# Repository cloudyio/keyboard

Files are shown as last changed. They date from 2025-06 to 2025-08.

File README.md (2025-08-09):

# Cloudboard



A low profile ergo keyboard inspired by the lily 58.

## Overview

The cloudboard is a small low profile keyboard made to be wireless and bluetooth, it features a lily 58 key layout, 110mAh batteriea im each half and 2 supermini controllers

The keyboard uses ZMK for its firmware due to how simple but effective it is for ergo and bluetooth keyboards.

## Why i made the project

Ive wanted to try out a ergo keyboard for a while now and thought it would be a fun idea to make one with the features i actually want and none of the extra parts.

## Features:

### Simple design

The keyboard is made to be clean and compact with each half only being less then 15cm long, the layout used is also concidered a intro ergo keyboard layout having many similarities to a normal layout which makes it easy to learn!


*Dev board risen to represent height of header*

### NRF52840 Board

The nice!nano is conciderably one of the best boards for a ergo split keyboard, this is due to its small size while still packing bluetooth compatibility, built in battery managment and USB C. One of the biggest issues with the board though is its 20 dollar price point so instead the keyboard uses a replicate alternative which includes **all** the features of the nice!nano (can be found in BOM below).



TLDR:

The dev board allows for bluetooth, usb c and battery managment for less than 4 dollars.

### Low profile

Low profile keyboard are better ergonimically, are smaller, lighter and arguably look better. The keyboard features choc v1 switches to give the board a even lower size profile and sound profile.



## Schematics/PCB

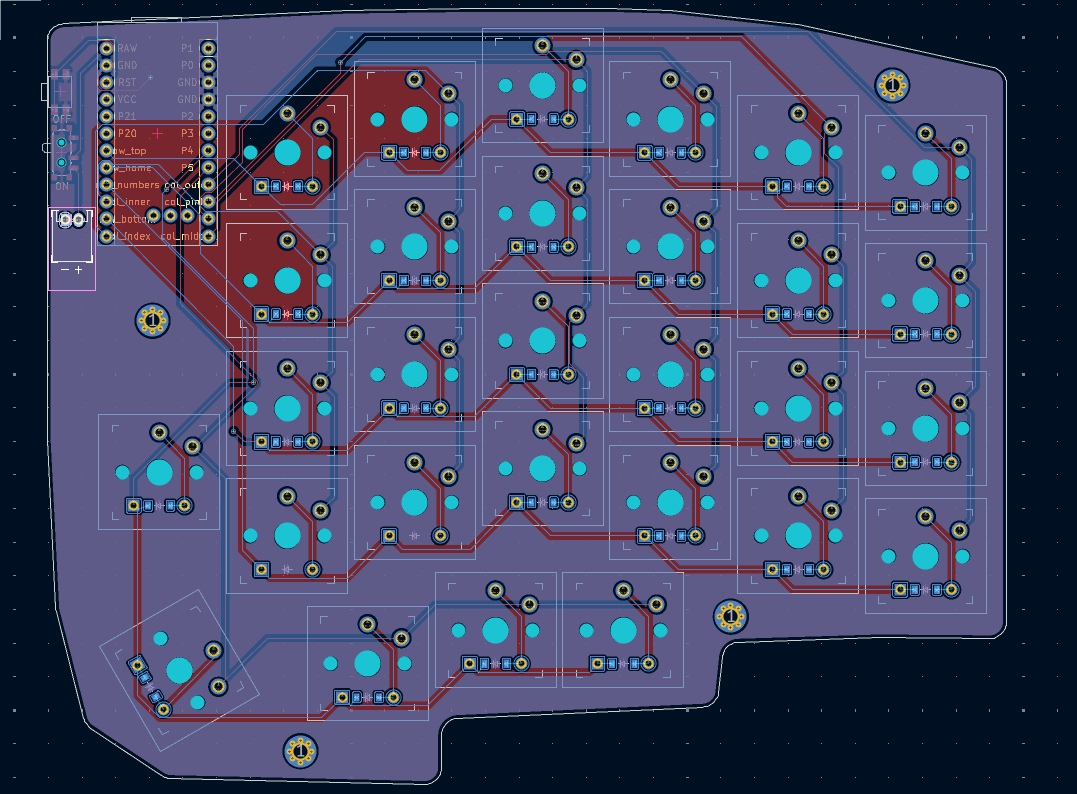
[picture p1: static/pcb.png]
pcb




Both schematics are the exact same





## BOM

| Item | Count | Price Per Item | Total Cost | Source | Notes |
|---|---|---|---|---|---|
| NRF52840 Development Board | 2 | $2.94 | $7.92 | [AliExpress](https://www.aliexpress.com/item/1005001621678794.html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) | Cheap nice!nano + shipping for all of aliexpress items |
| 1N4148 DO-35 Diodes | 1 | $1.58 | $1.58 | [AliExpress](https://www.aliexpress.com/item/1005007131309837.html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) | Diodes |
| Keycap Set | 1 | $32.47 | $32.47 | [AliExpress](https://www.aliexpress.com/item/1005007511714496.html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) | keycap set, quite good quality and look very nice, most price to performacnce i could find |
| JST battery connector  | 1 | $2 | $2 | [AliExpress](https://www.aliexpress.com/item/1005008970428474.html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) | Battery connector, comes with 2 |
| power switch | 1 | $2 | $2 | [AliExpress](https://www.aliexpress.com/item/1005006827258573.html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) | Also comes with 2 |
| Reset tactile button | 2 | $0 | $1 | [AliExpress](https://www.aliexpress.com/item/1005006292427731.html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) | Again, comes with 2 |
| Lithium Battery 110mAh | 1 | $8 | 8$ | [AliExpress](https://www.aliexpress.com/item/1005009279554068.html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) | Pretty cheap batteries, has the pcb integrated and fits under the dev board to stay hidden 2/pc |
| L+R PCB | 1 | $15.00 | $22.00 | [JLCPCB](https://cart.jlcpcb.com/quote?rand=0.6702360434866385) | Both pcbs, includes customs + shipping |
| Kailh Choc v1 Low Profile Switches | 1 | $38 | 38$ | [AliExpress](https://www.aliexpress.com/item/1005006626760418.html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) | Pretty good switches for a good price, only need 60 since keyboard is 58 keys |
| Black fillament | 1 | $18 | $25 | [Amazon](https://www.amazon.co.uk/gp/product/B0CD77VHBZ/ref=sw_img_1?smid=A2AC9IE1506MQ8&psc=1) | Grey fillament that's cheap, includes shipping |
| Heat inserts | 1 | $1.70 | $1.70 | [AliExpress](https://www.aliexpress.com/item/1005008666672949.html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) |  Heat inserts so fillament doesnt get destroyed, they annoyingly only come in 50 but there cheap so its fine anyway |
|  |  |  | $140.79 |  |  |
|  |  |  |  |  |  |
|  |  |  |  |  |  |
|  |  |  |  |  |  |
| |  |  |  |  |  |
notes:

- VAT is included but shipping is not since it varies, will typically end up at arround 7-15 dollars
- to save 5 dollars or so use the panel.zip gerber which is the 2 pcbs connected via mouse bites

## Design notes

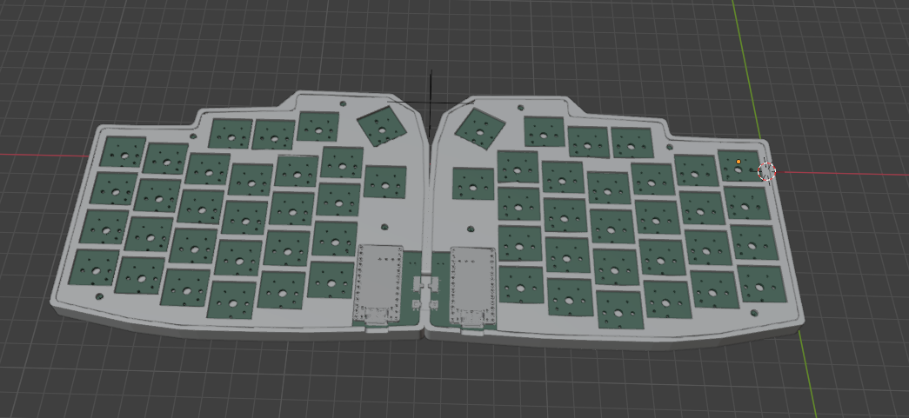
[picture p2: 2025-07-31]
static/image.png

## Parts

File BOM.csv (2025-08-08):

Item | Count | Price Per Item | Total Cost | Source | Notes
NRF52840 Development Board | 2 | $2.94 | $4.56 | https://www.aliexpress.com/item/1005001621678794.html?mp=1 | Cheap nice!nano
1N4148 DO-35 Diodes | 1 | $1.58 | $1.58 | https://www.aliexpress.com/item/1005007131309837.html?mp=1 | Diodes
Keycap Set | 1 | $32.47 | $32.47 | https://www.aliexpress.com/item/1005007511714496.html?mp=1 | keycap set, quite good quality and look very nice, most price to performacnce i could find
JST battery connector | 1 | $2 | $2 | https://www.aliexpress.com/item/1005008970428474.html?mp=1 | Battery connector, comes with 2
power switch | 1 | $2 | $2 | https://www.aliexpress.com/item/1005006827258573.html?mp=1 | Also comes with 2
Reset tactile button | 1 | $0 | $1 | https://www.aliexpress.com/item/1005006292427731.html?mp=1 | Again, comes with 2
Lithium Battery 110mAh | 1 | $8 | 8$ | https://www.aliexpress.com/item/1005009279554068.html?mp=1 | Pretty cheap batteries, has the pcb integrated and fits under the dev board to stay hidden 2/pc
L+R PCB | 1 | $15.00 | $22.00 | https://cart.jlcpcb.com/quote?rand=0.6702360434866385 | Both pcbs, includes customs + shipping
Kailh Choc v1 Low Profile Switches | 1 | $38 | 38$ | https://www.aliexpress.com/item/1005006626760418.html?mp=1 | Pretty good switches for a good price, only need 60 since keyboard is 58 keys
Black fillament | 1 | $18 | $18 | https://a.co/d/5nH2rc7 | Grey fillament thats cheap, only one i could find in budget
Heat inserts | 1 | $1.70 | $1.70 | https://www.aliexpress.com/item/1005008666672949.html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 | Heat inserts so fillament doesnt get destroyed, they annoyingly only come in 50 but there cheap so its fine anyway
 |  |  | $130.42

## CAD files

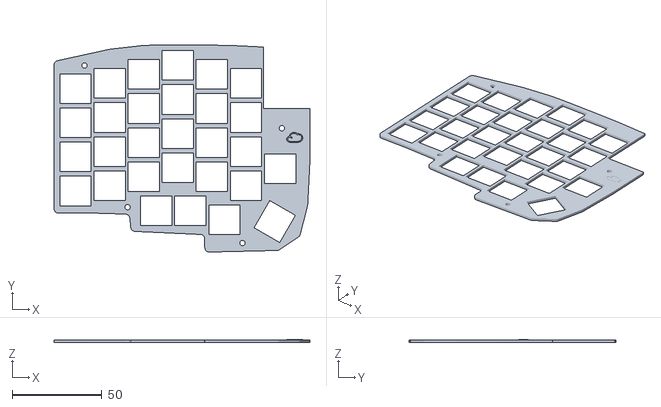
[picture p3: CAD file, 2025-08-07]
production/left/case/PlateL.stl
142.6 x 115.4 x 1.85

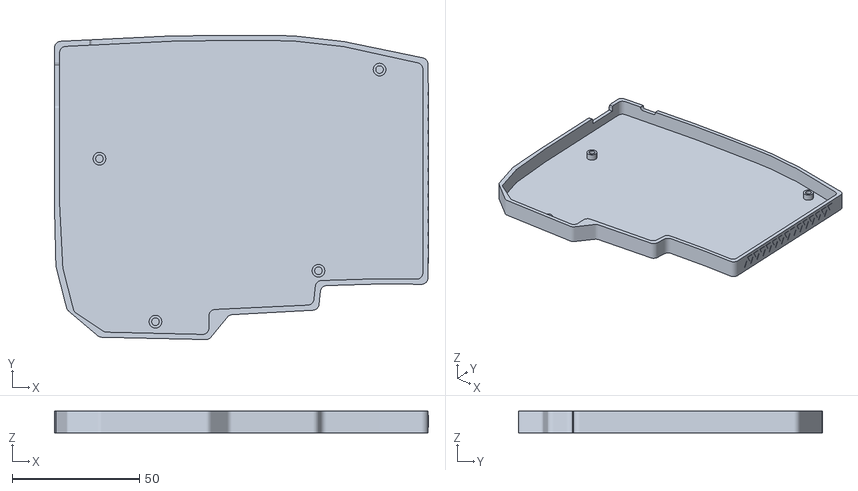
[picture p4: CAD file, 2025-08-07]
production/right/case/CaseR.stl
146.9 x 119.4 x 8.50

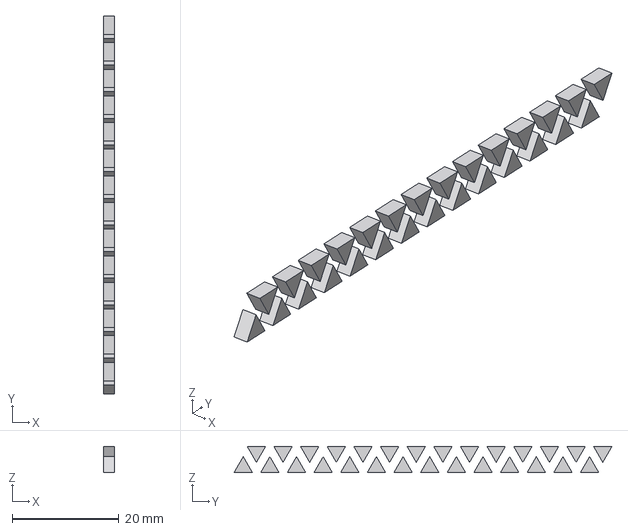
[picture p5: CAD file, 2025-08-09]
source/cad/CaseL.step
2.00 x 70.9 x 4.91 mm
Folder 54
Imported

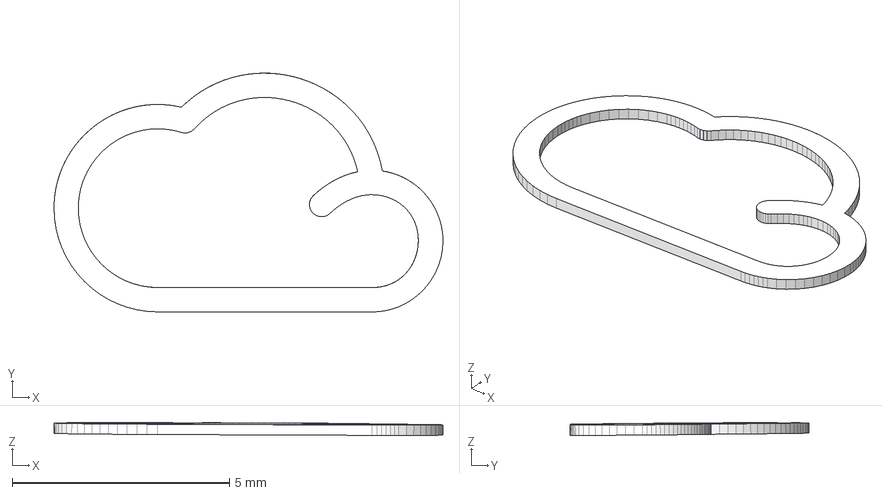
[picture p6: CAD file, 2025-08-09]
source/cad/PlateR.step
8.96 x 5.50 x 0.296 mm

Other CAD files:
production/left/case/CaseL.stl
production/right/case/PlateR.stl
source/cad/PlateL.step
source/cad/CaseR.step

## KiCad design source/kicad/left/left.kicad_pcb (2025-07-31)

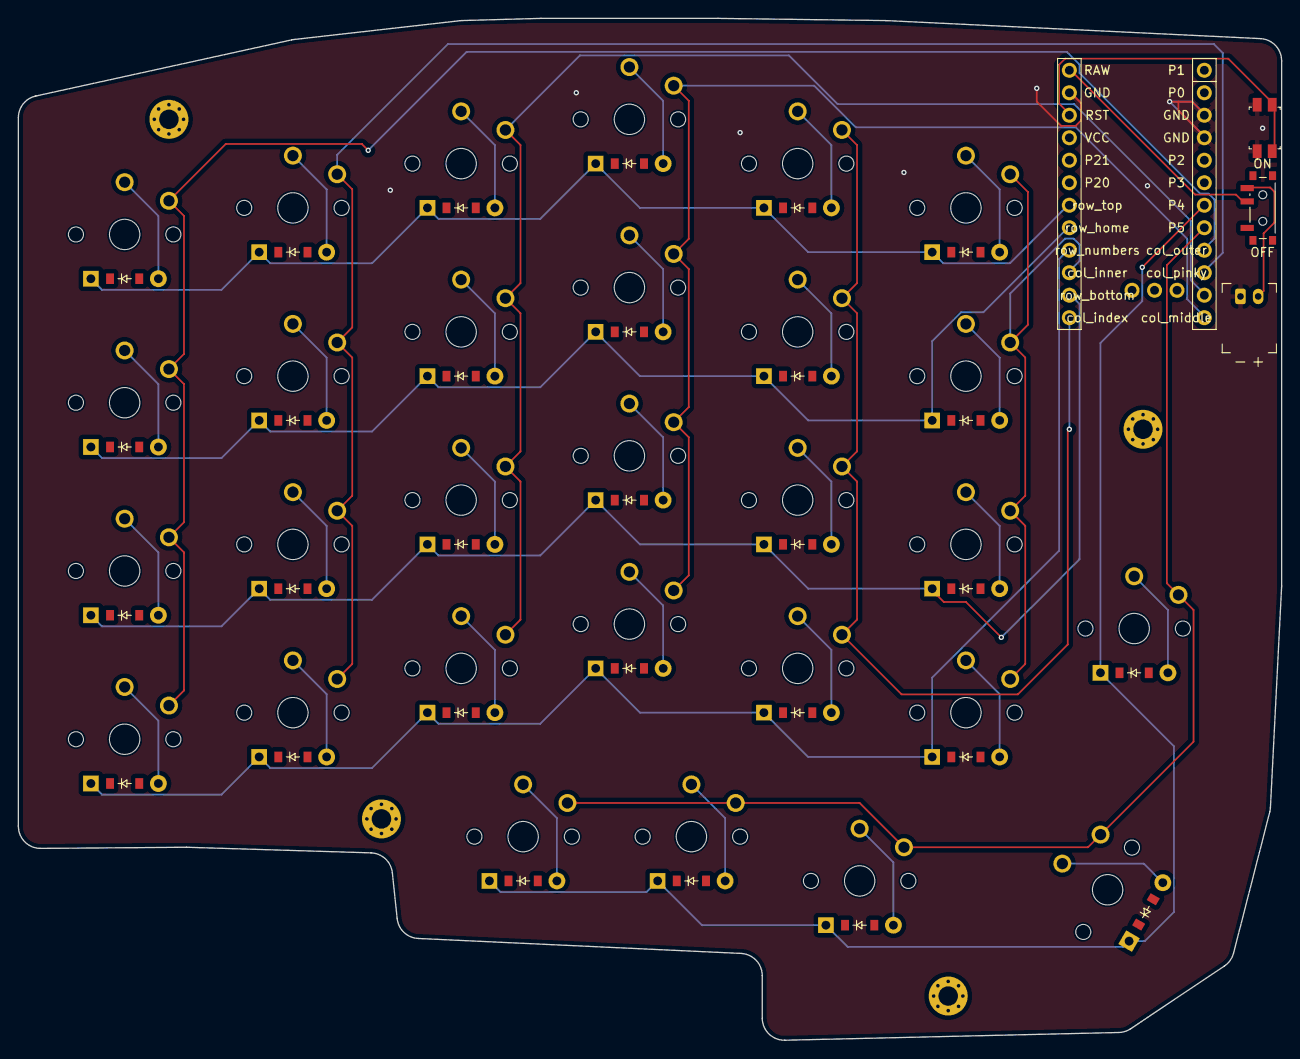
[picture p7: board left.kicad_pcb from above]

Board: 2 copper layers, 142.7 x 115.4 mm, 66 parts (0 on the bottom side), 45 nets.

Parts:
D1, D2, D3, D4, D5, D6, D7, D8, D9, D10, D11, D12, D13, D14, D15, D16, D17, D18, D19, D20, D21, D22, D23, D24, D25, D26, D27, D28, D29: ComboDiode
JST1: battery_connector_jst_ph_2
MCU1: mcu_supermini_nrf52840
PWR1: power_switch_smd_side
RST1: reset_switch_smd_side
S1, S2, S3, S4, S5, S6, S7, S8, S9, S10, S11, S12, S13, S14, S15, S16, S17, S18, S19, S20, S21, S22, S23, S24, S25, S26, S27, S28, S29: PG1350
_1, _2, _3, _4: MountingHole_2.2mm_M2_Pad_Via

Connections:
BAT_P: JST1.2, PWR1.3
GND: JST1.1, MCU1.3, MCU1.4, MCU1.23, RST1.2, RST1.4
RAW: MCU1.24, PWR1.2
RST: MCU1.22, RST1.1, RST1.3
center_only: D26.2, S26.2
col_index: MCU1.13, S17.1, S18.1, S19.1, S20.1
col_inner: MCU1.15, S21.1, S22.1, S23.1, S24.1
col_middle: MCU1.12, S13.1, S14.1, S15.1, S16.1
col_outer: MCU1.9, S1.1, S2.1, S3.1, S4.1
col_pinky: MCU1.10, S5.1, S6.1, S7.1, S8.1
col_ring: MCU1.11, S9.1, S10.1, S11.1, S12.1
extra_col: MCU1.8, S25.1, S26.1, S27.1, S28.1, S29.1
extra_key: D29.2, S29.2
extra_row: D25.1, D26.1, D27.1, D28.1, D29.1, MCU1.7
index_bottom: D18.2, S18.2
index_home: D19.2, S19.2
index_numbers: D17.2, S17.2
index_top: D20.2, S20.2
inner_bottom: D22.2, S22.2
inner_home: D23.2, S23.2
inner_numbers: D21.2, S21.2
inner_top: D24.2, S24.2
left_only: D25.2, S25.2
macro_key: D28.2, S28.2
middle_bottom: D14.2, S14.2
middle_home: D15.2, S15.2
middle_numbers: D13.2, S13.2
middle_top: D16.2, S16.2
outer_bottom: D2.2, S2.2
outer_home: D3.2, S3.2
outer_numbers: D1.2, S1.2
outer_top: D4.2, S4.2
pinky_bottom: D6.2, S6.2
pinky_home: D7.2, S7.2
pinky_numbers: D5.2, S5.2
pinky_top: D8.2, S8.2
right_only: D27.2, S27.2
ring_bottom: D10.2, S10.2
ring_home: D11.2, S11.2
ring_numbers: D9.2, S9.2
ring_top: D12.2, S12.2
row_bottom: D2.1, D6.1, D10.1, D14.1, D18.1, D22.1, MCU1.14
row_home: D3.1, D7.1, D11.1, D15.1, D19.1, D23.1, MCU1.17
row_numbers: D1.1, D5.1, D9.1, D13.1, D17.1, D21.1, MCU1.16
row_top: D4.1, D8.1, D12.1, D16.1, D20.1, D24.1, MCU1.18

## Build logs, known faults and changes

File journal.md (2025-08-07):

---
title: "Cloudboard"
author: "Cloudy"
description: "A small low profile keyboard!"
created_at: "2025-06-14"
time spent: "27.25h"
---

# June 14th:

I did basic research on what goes into making a low profile keyboard and the differences when designing it, i decided on a wired keyboard since i want it to be small and it is generally just easier to design a wired one, i also found a 75% to be the best for me. Picture of layout below:

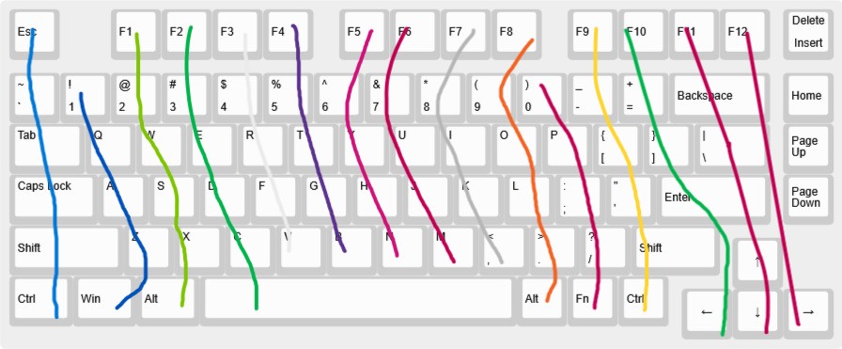
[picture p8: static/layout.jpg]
keyboard layout


**Total time spent: 1h**

# June 16th:

Did more research and resetup kicad, i looked through a bunch of boards and found the nice!nano, the nice!nano honestly seemed great for the build but costing arround 30$ for a microcontroller seemed like a bad idea, i went back to look for another board and ended up finding this:

[Supermini NRF52840](https://www.aliexpress.com/item/1005006019812115.html)
This is a really good alternative to the nice nano, it is considered Nice!Nano compatible meaning any info i find on the nice!nano will be relevant to this board, also significantly cheaper then the other board coming in at ￡ 7.79

One of the main reasons i really like this board is the fact it is bluetooth and has charging managment, making my life much easier and brings bluetooth back as an option.

I also did look for a dongle reciver and stumbled across the [nRF52840 Dongle](https://www.nordicsemi.com/Products/Development-hardware/nRF52840-Dongle), it is zmk compatible which is one of the main reasons its good but i dislike the bulkyness and think ill keep looking

**Total time spent: 1h**

# June 26th:

Designed the schematic in kicad and changed the layout



the new layout adds more functionality and buttons but im stuck on how i am going to fit the dev board on the new design, i also created the key layout schematic in kicad:



but the dev board i am using has one less gpio pin to what i need so i either need to pick a dev dev board, not use a dev board at all or optimise the matrix more.
i also researched some stiff on the material and came to the realisation that having my case cnc'd would be way to expensive. So right now i am planning on 3d printing it with a unique stratergy with nylon using a 3d printing method called MJF, i think it will come to arround 60 dollars but i can only tel when my case is done

**Total time spent: 3h**

# June 28th:

I came to the realisation that a dev board just wouldnt fit and the keyboard wouldnt be as compact as a wanted if i wanted to use one, so i am now embedding the microcontroller on to the pcb. I started with adding a usb c receptacle but kept hitting more and more issues as i went along, i ended up with this after 3 hours of work:

What i tried to do was use a IC to controll the battery so the battery wasnt charging all the time and the keyboard could either be wired or wireless, i also plan to use a 2 pin battery connector in case i ever need to replace the battery. Overall it has been very overwhelming and ill come back to it later because im 80% sure it wont work. I am now also using [ai03s guide](https://wiki.ai03.com/books/pcb-design) to try and simplify what i need to do.

**Total time spent: 3.5h**

# July 2nd

Still working on embedding the microcontroller, found ai03s guide very helpful and ended up with this

This was great progress and everything seemed like it worked, the guide was very helpful at explaining what things did and what to do next but i quickly ran into the issue of running out of gpio pins, the microcontroller i was using (ATmega32U4) just didnt have enough pins unless i wanted to optimise my matrix. This really wasnt great as i wanted to make designing the pcb itself after the schematic as easy as possible and didnt want routes all over the place.

I then decided on the rp2040 which had enough io pins for the layout i wanted. I found [this guide](https://www.youtube.com/watch?v=6Z49bynRqj8) very helpful at the begining as it showed how to correctly wire the microcontroller with the crystal and flash memory along with a usb c port. After following i ended up with this:



# July 6th

Havent posted a log for a while because it has been very on and off, i have pretty much decided on the FINAL mcu i will use for the keyboard, the [MDBT50Q-1MV2](https://www.raytac.com/product/ins.php?index_id=24), it has everything i need like a built in antenna and a usb interface making my life so much easier. Appart from that it has just been integrating everything from past designs into one complete circuit, making this:



**Total time spent: 2h**

# July 9th

Ive been working on routing the pcb and have got to this point:



This is great progress for me and the pcb is fully complete now, unless i add drill holes later. The keyboard uses a GND filled zone, this is to make the routing neater in general and can help with heat. Ive puposefully moved all the smd parts to the back since i am planning on getting them assembled, this is due to me not being skilled enough at soldering to properly soldier the parts properly. 3d render of the pcb:



Getting the board assembeled might be expensive though. just on jlcpcb alone your required to assemble at least 2 boards which quoted me at arround 50 dollars for 2 assembled boards, 3 empty.

**Total time spent: 3h**

# July 11th

Once again ive decided to full 180 which is really unfortunate, the mcu module i was using was out of stock on jlcpcb and since there were pins on the underside, it wouldnt be possible to soldier myself. Ive decided to back track a bit and will use the Supermini, the nice!nano clone to allow for a bluetooth keyboard. I am gonna create a ergo keyboard instead and will base it off the lily 58 layout, the lilly 58 is a entry level ergo split keyboard and is a great place to start.



the reason it is entry level is due to the amount of keys it has which can remove efficiency but i think it will be fine. The pcb will be way easier to create then the other one and i will have to start from scratch but i am happy to switch over to this idea.

**Total time spent: 1h**

# July 11th

Fully finished the schematic, i was gonna use 2 oled displays but then checked zmk's battery profiler and decided against it, this is because it would cut my battery life down by 7 times which isnt really what i want. I made 2 different matrixes for each half of the keyboard along with their own microcontrollers since better battery life + the microcontrollers are cheap so its actually easier this way



**Total time spent: 2h**

# July 15th

Left hand side pcb is done! Im happy with how it turned out. Designing the first keyboard helped quite alot in routing this one and hope it works well, just need to copy it over for the right hand side now and i can start working on the case which i think will be the hardest part



**Total time spent: 1h**

# July 30th

After a couple weeks of procrastinating, designing in kicad became too much, it was impossible to flip the keyboard onto its right side due to the way everything is set out and i became stuck and just used ergogen. Ergogen wasnt really much easier as i found little documentation for stuff, i honestly dont know how much time i spent researching small things but it was too long so im only going to count the time it took inside of the editor. I currently have a roughly 400 line config which defines the switch layout, pcb and a bit of the case, i still need to add screws and wire the pcb but ergogen was a great help and allows for a perfectly symetrical keyboard





[This guide](https://flatfootfox.com/ergogen-part4-footprints-cases/) was a great help in making this but ergogen still takes a huge amount of time and isnt as proficient as using your standard tools

**Total time spent: 4h**

# July 31st

Finished everything appart from firmware, it turns out that ergogen doesnt generate the other half of your keyboard! This was really annoying and i had to flip positions in kicad using a script i found. But finally after all the issues the case is done with its correct cutouts and both halfs of the pcb are wired and filled correctly!:



Now all that needs to be done is firmware then the project will be fully complete.

**Total time spent: 2.5h**

# July 31st

Final journal until i make it physically! i setup the firmware which was quite easy because it uses a lilly 58 format so everything is done and ready now, i am very pleased with the results and the github is now fully populated.

**Total time spent: 2h**

# August 6th
Added more to the case and plate as per request, added a triangle patter to the sides anda little cloud on the top! also semi rendered it so it looks better on the readme, all changes can be viewed straight from readme, BOM was also updated the day prior but i dont think it deserves its own journal log

**Total time spent: 0.75h**

# August 7th
Realised how void my readme was and went through the checklist realising i was more stuff, i added switches to my cad to give a better idea om how it will look and got a couple good screenshots, enhanced the features section and gave more description on pretty much everything

**Total time spent: 0.5h**

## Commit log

2025-08-05 added case and made panel for cheaper production
    [CaseL.stl, CaseR.stl, PlateL.stl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]
2025-08-07 added shapr file just in case
2025-08-07 moved all CAD into a CAD folder
    [case.step, plate.step]
2025-08-07 Wanted to make sure everything was correct
    [Case.stl, CaseL.stl, CaseR.stl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]
2025-08-08 updated bom
    [BOM.csv]
2025-08-09 Not using typeractive anymore so don’t need them there
2025-08-09 Fixed .step files
    [CaseL.step, CaseR.step, PlateL.step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]
